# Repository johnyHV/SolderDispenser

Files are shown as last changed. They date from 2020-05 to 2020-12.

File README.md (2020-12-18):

# Solder paste dispenser

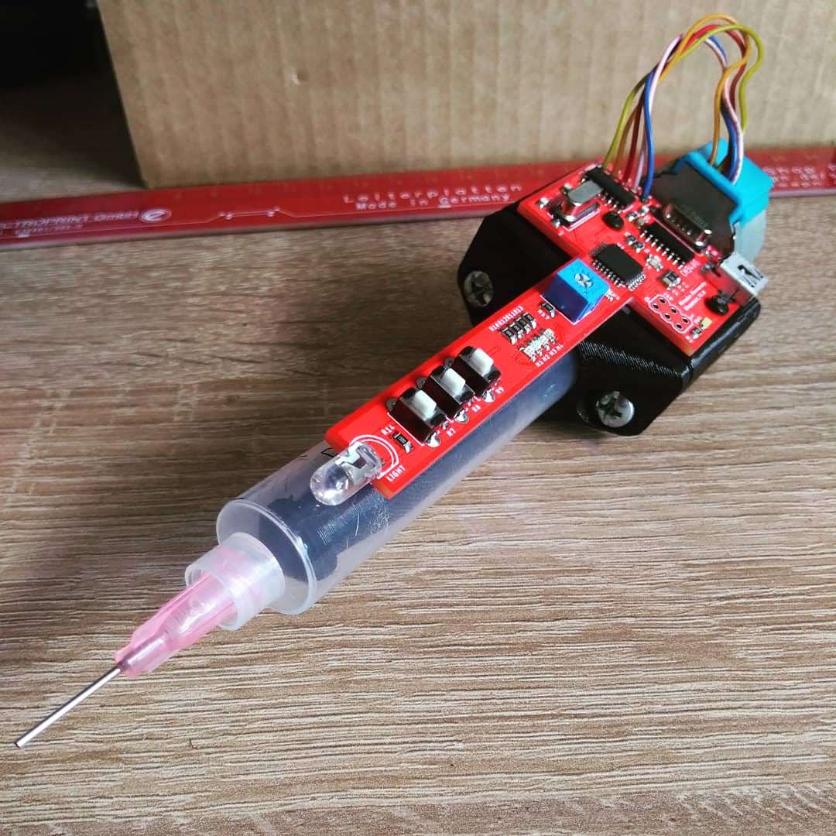
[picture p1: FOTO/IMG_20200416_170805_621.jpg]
Image description


# Change Log

### Version 1.1 [HW v1.1, SW v1.1]
- pridana funkcia auto pull efektu. Toznamena, ze po pusteni PUSH tlacidla sa krokovy motor otoci o X krokov spat, vdaka comu prestane tlacit na spajkovaciu pastu. Efekt mozete zapnut pomocou definicie **M_A_PULL_E** v subore **MCU_cfg.h**.  Definiciou **M_A_PULL_ST** nastavujete pocet krokov o kolko sa krokov motor vrati spet. Tuto hodnotu je potrebne odladit pre kazdeho uzivatela, no myslim ze 100 krokov bude dost. Definiciou **M_A_PULL_SP** nastavite rychlost otacania krokoveho motora, pri otacani.
- pridany vypis SW verzie do konzoly
- aktualizovana doxygen dokumentacia

### Version 1.2 [HW v1.1, SW v1.2]
- pridana moznost zapnutia/vypnutia auto pull modu pomocou tlacidiel.  Defaultne je auto pull mod vypnuty, pomocou definicie **M_A_PULL_E**. Pre zapnutie je potrebne podrzat 5 sekund tlacidlo **MODE**. Po 5 sekundach zsvieti led **STATUS** na 1 sekundu. Vtedy je potrebne pustit tlacidlo **MODE**. Touto sekvenciou bol zapnuty auto pull mod. Ak ho chcete vypnut, znova je potrebne podrzat 5 sekund tlacidlo  **MODE**. Volba zapnutia/vypnutia auto pull modu sa neuklada do EEPROM pamete, cize po kazdom restarte je nastavena na hodnotu v definicii **M_A_PULL_E**.
- aktualizacia doxygen dokumentacie

### Version 1.3 [HW v1.2, SW v1.2]
- pridany kondenzator 1uF k napajaniu MCU

### Version 1.4 [HW v1.3, SW v1.2]
- pridany kondenzator 100nF k CH340 na 3,3V vystup.

# Bug

### Bug 0001
**Opis chyby:** 
chyba v HW zapojeni pre HW verzie 1.0, 1.1, 1.2. Chybajuci kondenzator 100nF pre CH340 na pine 4, proti zemi.

**Spravanie chyby:**
- OS moze mat problem pri detegcii zariadenia, v pripade pouzitia dlheho USB kabla. Pri dlzke kabla do 20cm bude zariadenie fungovat korektne.
- Moze vzniknut problem pri programovani MCU, kedy OS vypise hlasku nedetegovaneho USB zariadenia.
- Nahodne restarty MCU pocas pouzivania podavaca

**Riesenie:**
- potrebne prispajkovat kondenzator 100nF na pin 4 integrovaneho obvodu CH340 proti zemi. Tak ako je to zobrazene na fotografii
Image description

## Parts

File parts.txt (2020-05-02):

https://www.tme.eu/sk/details/b4_bn1052/zavitove-vlozky/bossard/m4-bn1052/
https://www.tme.eu/sk/details/mx-54819-0519/konektory-usb-a-ieee1394/molex/54819-0519/
https://www.tme.eu/sk/details/3362p-1-103lf/potenciometre-jednootackove-tht/bourns/
https://www.tme.eu/sk/details/uln2003adr/drivery-integrovane-obvody/texas-instruments/
https://www.tme.eu/sk/details/1825965-1/ostatne-prepinace-a-kontrolky/te-connectivity/
https://www.tme.eu/sk/details/16.00m-smdhc49s-ht/krystalove-rezonatory-smd/yic/16mhz-105c-49smd-on-tape/
https://www.tme.eu/sk/details/12.00m-smdhc49s/krystalove-rezonatory-smd/yic/
https://www.tme.eu/sk/details/b4x20_bn1435/skrutky/bossard/1219995/
https://www.tme.eu/sk/details/c0805c220j5gac/kondenzatory-mlcc-smd-0805/kemet/c0805c220j5gactu/

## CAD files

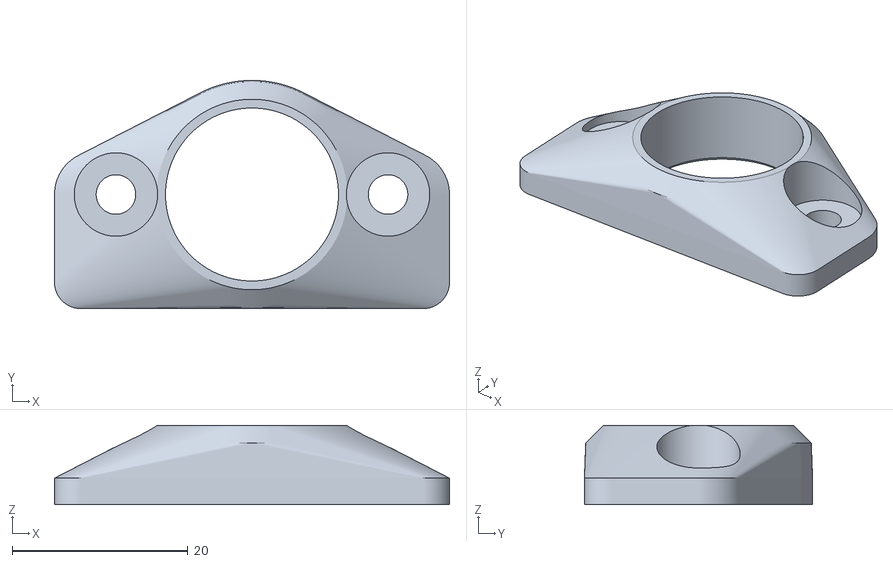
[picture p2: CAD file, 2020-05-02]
3D/syringe_18.6mm.stl
45.0 x 26.0 x 9.00

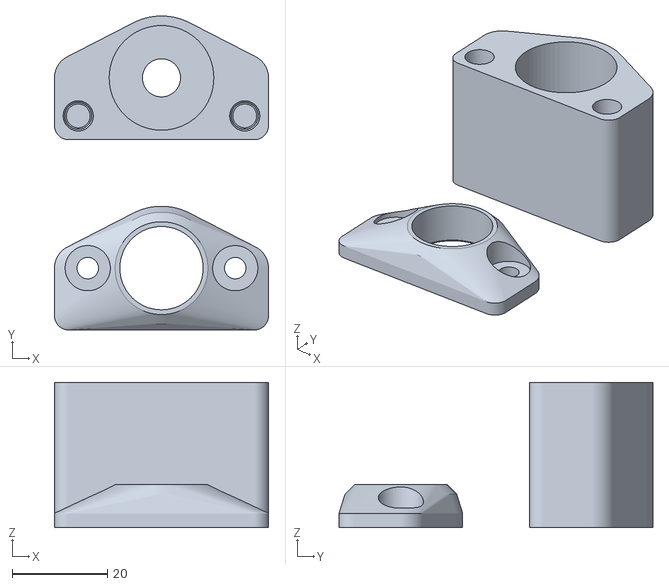
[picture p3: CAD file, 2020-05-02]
3D/motor_mount.stl
45.0 x 66.0 x 30.5

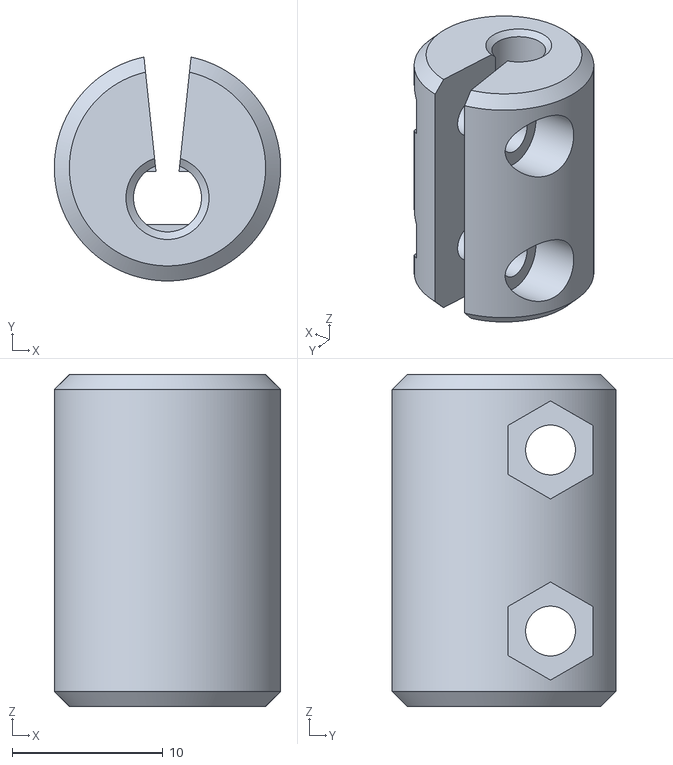
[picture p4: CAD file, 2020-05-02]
3D/coupler.stl
15.0 x 14.8 x 22.0

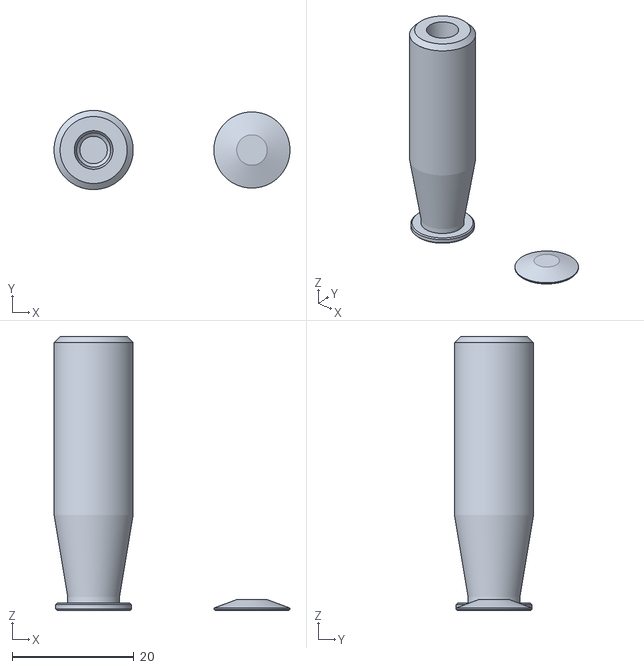
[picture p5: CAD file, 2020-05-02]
3D/plunger.stl
38.8 x 13.0 x 45.0

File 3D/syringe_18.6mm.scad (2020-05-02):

// This file generates two parts, the motor mount and a matching syringe holder plate.
// The motor mount has holes for 4 M4 threaded inserts, McMaster 94180A353. Push them
// in with a standard solder iron. Make sure to push 1-2 mm at a time, letting the 
// plastic part to cool down.

$fn=180;

shaft_hole_diameter = 8;

bottom_height = 2.5;
motor_mount_width = 45;

cavity_wall = 2;
cavity_height = 28;
cavity_diameter = 22;

motor_screws_space = 35;
motor_screws_holes_offset = 8;
motor_screws_holes_depth = 20;

syringe_screws_space = 31;
syringe_screws_holes_depth = 20;

total_height = bottom_height + cavity_height;

base_corner_radius1 = 5;  // convex side
base_corner_radius2 = 3;  // flat side
base_corner_offset  = 0;

syringe_holder_height1 = 3;
syringe_holder_height2 = 6;
syringe_hole_diameter = 18.7+1.0;
syringe_hole_wall = 3;

syringe_holder_screw_diameter = 4.0+0.5;
syringe_holder_screw_head_diameter = 9.0+0.5;

chamfer = 0.5;

eps1 = 0.001;
eps2 = 2*eps1;

// Hole for a M4 metal insert, mcmaster part number 94180A353.
// h is the total depth for the screw hole. Already includes an 
// extra eps1 at the opening side.
module m4_threaded_insert(h) {
  // Adding tweaks for compensate for my printer's tolerace.
  A = 5.3 + 0.3;
  B = 5.94 + 0.4;
  L = 7.9;
  D = 5.0;
  translate([0, 0, -eps1]) {
    // NOTE: diameter are compensated to actual print results.
    // May vary among printers.
    cylinder(d1=B, d2=A, h=eps1+L*2/3, $f2=32);
    cylinder(d=A, h=eps1+L, $f2=32);
    translate([0, 0, L-eps1]) cylinder(d=D, h=h+eps1-L, $f2=32);
  }
}

// c1, c2 are chamfers at bottom and top respectivly. s1, s2 are chamfers's slopes.
module chamfered_cylinder(d, h, c1, s1, c2, s2) {
    cylinder(d1=d-2*c1, d2=d, h=s1*c1);
    translate([0, 0, s1*c1-eps1]) cylinder(d=d, h=h-s1*c1-s2*c2+eps2);
    translate([0, 0, h-s2*c2]) cylinder(d1=d, d2=d-2*c2, h=s2*c2);
}

module motor_holes() {
  translate([motor_screws_space/2, -motor_screws_holes_offset, total_height]) 
      rotate([180, 0, 0]) 
      m4_threaded_insert(motor_screws_holes_depth);

 translate([-motor_screws_space/2, -motor_screws_holes_offset, total_height]) 
      rotate([180, 0, 0]) 
      m4_threaded_insert(motor_screws_holes_depth);
}

module syringe_screws() {
  translate([syringe_screws_space/2, 0, -eps1]) 
      m4_threaded_insert(syringe_screws_holes_depth);
  
  translate([-syringe_screws_space/2, 0, -eps1]) 
       m4_threaded_insert(syringe_screws_holes_depth);
}

// Hole at the bottom of the base for the shreded shaft.
module shaft_hole() {
 translate([0, 0, -eps1]) cylinder(d=shaft_hole_diameter, h=bottom_height+eps2, $f2=32);
}

// The motor mount before any substraction. It accepts a height parameter so 
// we can use this pattern also for the syringe holder.
module base_pattern(h) {
  hull() {
    cylinder(d=cavity_diameter+2*cavity_wall, h=h);
    
    // Flat side
    translate([motor_mount_width/2-base_corner_radius2, -(cavity_diameter+2*cavity_wall)/2+base_corner_radius2, 0]) cylinder(r=base_corner_radius2, h=h);
    
    translate([-(motor_mount_width/2-base_corner_radius2), -(cavity_diameter+2*cavity_wall)/2+base_corner_radius2, 0]) cylinder(r=base_corner_radius2, h=h);
    
    // Concave side
    translate([motor_mount_width/2-base_corner_radius1, base_corner_offset, 0]) 
        cylinder(r=base_corner_radius1, h=h);
    
    translate([-(motor_mount_width/2-base_corner_radius1), base_corner_offset, 0]) 
        cylinder(r=base_corner_radius1, h=h);
  }
}

// The coupler cavity cut.
module cavity() {
  translate([0, 0, bottom_height]) cylinder(d=cavity_diameter, h=total_height, $fn=64);  
}

module motor_mount() {
  difference() {
    base_pattern(total_height);
    cavity();
    shaft_hole();
    motor_holes();
    syringe_screws();
  }
}

module syringe_holder_blank() {
  hull() {
    translate([0, 0, syringe_holder_height1]) rotate([0, 180, 0]) 
        base_pattern(syringe_holder_height1);
  
    chamfered_cylinder(syringe_hole_diameter+2*syringe_hole_wall, syringe_holder_height1+syringe_holder_height2, eps1, 1.0, 2.0, 1.0);
  } 
}

module syringe_holder() {
  total_h=syringe_holder_height1+syringe_holder_height2+eps2;
  difference() {
    syringe_holder_blank();
    
    // Syringe hole + chamfer;
    translate([0, 0, -eps1]) {
      cylinder(d=syringe_hole_diameter, h=total_h+eps2);
      cylinder(d1=syringe_hole_diameter + 2*chamfer, d2=eps1, 
          h=(syringe_hole_diameter + 2*chamfer)/2);
    }
    
    
    
    // Screw holes + chamfers.
    translate([-syringe_screws_space/2, 0, -eps1]) {
      cylinder(d=syringe_holder_screw_diameter, h=total_h+eps2);
      cylinder(d1=syringe_holder_screw_diameter + 2*chamfer, d2=eps1, 
          h=(syringe_holder_screw_diameter + 2*chamfer)/2);
    }
    
    translate([syringe_screws_space/2, 0, -eps1]) {
      cylinder(d=syringe_holder_screw_diameter, h=total_h+eps2);
      cylinder(d1=syringe_holder_screw_diameter + 2*chamfer, d2=eps1, 
          h=(syringe_holder_screw_diameter + 2*chamfer)/2);
    }
    
    // Screw heads insets.
    translate([-syringe_screws_space/2, 0, syringe_holder_height1]) 
        cylinder(d=syringe_holder_screw_head_diameter, h=syringe_holder_height2+eps2);
    
    translate([syringe_screws_space/2, 0, syringe_holder_height1]) 
        cylinder(d=syringe_holder_screw_head_diameter, h=syringe_holder_height2+eps2);
  }  
}

module main() {
  //motor_mount();
  translate([0, -40, 0]) syringe_holder();
}

main();

 

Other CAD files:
3D/motor_mount.scad
3D/coupler.scad
3D/plunger.scad

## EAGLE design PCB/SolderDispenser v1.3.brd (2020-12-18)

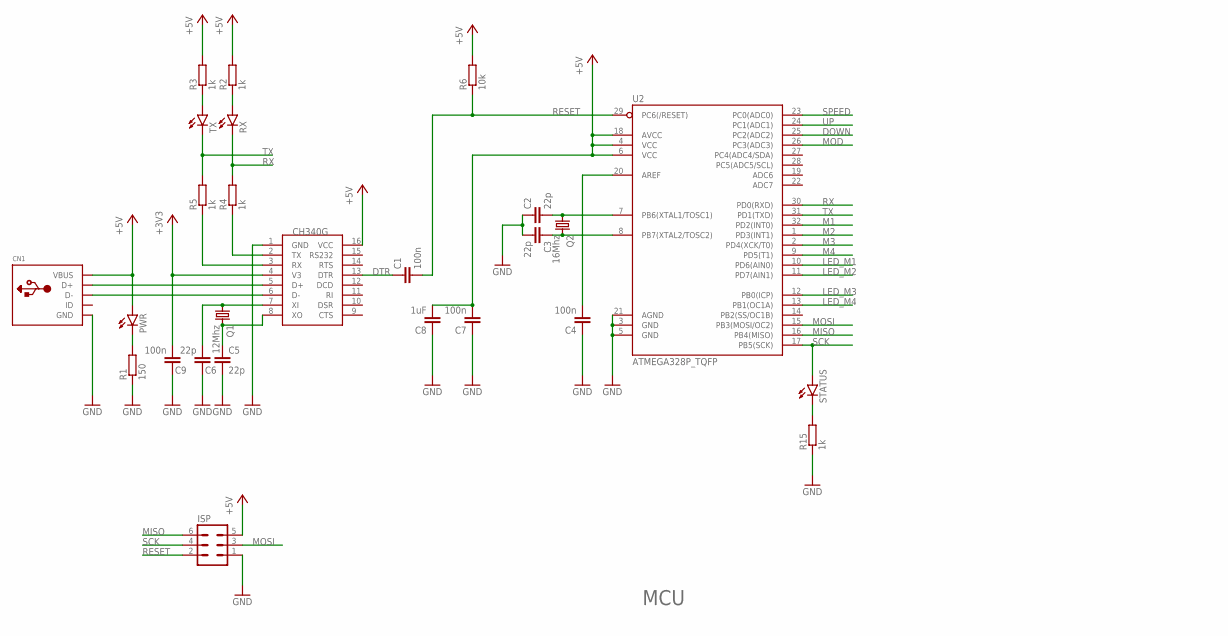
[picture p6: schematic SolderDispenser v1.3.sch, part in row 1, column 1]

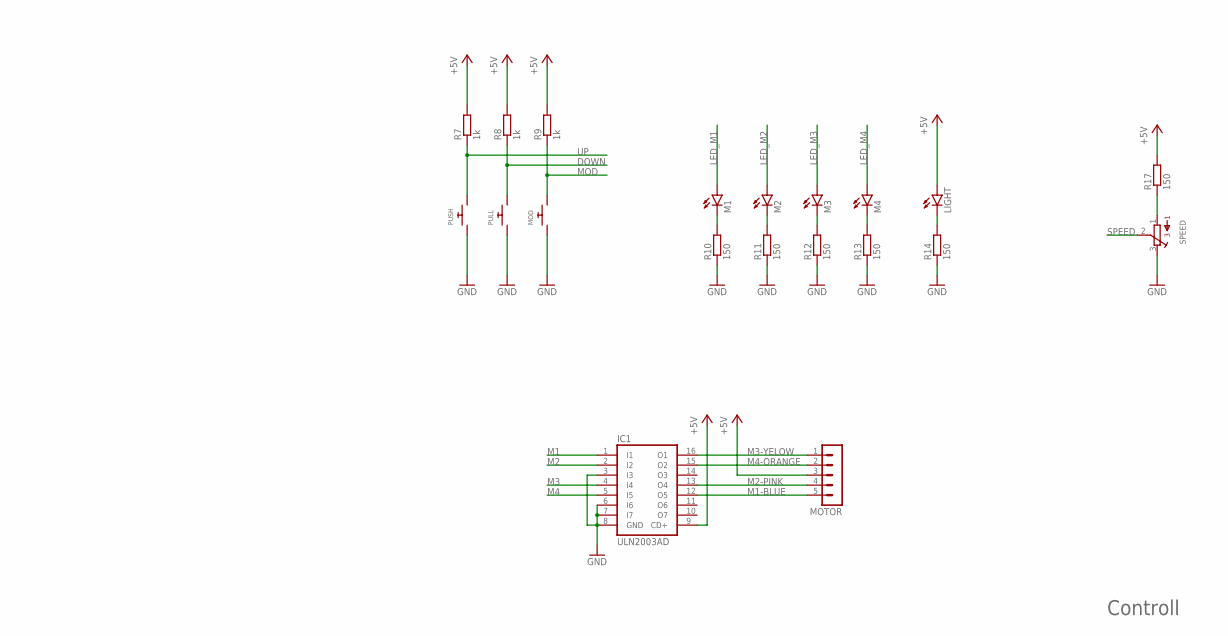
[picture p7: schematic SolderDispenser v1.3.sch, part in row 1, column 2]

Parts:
C1, C4, C7, C9: 100n; C0805
C2, C3, C5, C6: 22p; C0805
C8: 1uF; C0805
CN1: USBMOLEX; USB-MINIB-THM-MOLEX
IC1: ULN2003AD; SO16
ISP: MA03-2
LIGHT: LED5MM
M1, M2, M3, M4: LEDSML0805; SML0805
MOD: SWITCH_PUSHBUTTONEVQ-PE; TACT_PANA-EVQ
MOTOR: MA05-1
PULL: SWITCH_PUSHBUTTONEVQ-PE; TACT_PANA-EVQ
PUSH: SWITCH_PUSHBUTTONEVQ-PE; TACT_PANA-EVQ
PWR: LEDSML0805; SML0805
Q1: 12Mhz; HC49UP
Q2: 16Mhz; HC49UP
R1, R10, R11, R12, R13, R14, R17: 150; R0805
R2, R3, R4, R5, R7, R8, R9, R15: 1k; R0805
R6: 10k; R0805
RX: LEDSML0805; SML0805
SPEED: 3362P
STATUS: LEDSML0805; SML0805
TX: LEDSML0805; SML0805
U2: ATMEGA328P_TQFP; TQFP32-08
U$1: CH340G; SOIC16

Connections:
+3V3: C9.2, U$1.4 (V3)
+5V: C7.2, C8.2, CN1.VBUS, IC1.9 (CD+), ISP.5, LIGHT.A, MOTOR.3, PWR.A, R2.2, R3.2, R6.2, R7.2, R8.2, R9.2, R17.2, U2.4 (VCC), U2.6 (VCC), U2.18 (AVCC), U$1.16 (VCC)
DOWN: PULL.P$2, R8.1, U2.25 (PC2(ADC2))
DTR: C1.1, U$1.13 (DTR)
GND: C2.1, C3.2, C4.1, C5.2, C6.1, C7.1, C8.1, C9.1, CN1.GND, IC1.3 (I3), IC1.6 (I6), IC1.7 (I7), IC1.8 (GND), ISP.1, MOD.P$1, PULL.P$1, PUSH.P$1, R1.1, R10.1, R11.1, R12.1, R13.1, R14.1, R15.1, SPEED.3, U2.3 (GND), U2.5 (GND), U2.21 (AGND), U$1.1 (GND)
LED_M1: M1.A, U2.10 (PD6(AIN0))
LED_M2: M2.A, U2.11 (PD7(AIN1))
LED_M3: M3.A, U2.12 (PB0(ICP))
LED_M4: M4.A, U2.13 (PB1(OC1A))
M1: IC1.1 (I1), U2.32 (PD2(INT0))
M1-BLUE: IC1.12 (O5), MOTOR.5
M2: IC1.2 (I2), U2.1 (PD3(INT1))
M2-PINK: IC1.13 (O4), MOTOR.4
M3: IC1.4 (I4), U2.2 (PD4(XCK/T0))
M3-YELOW: IC1.16 (O1), MOTOR.1
M4: IC1.5 (I5), U2.9 (PD5(T1))
M4-ORANGE: IC1.15 (O2), MOTOR.2
MISO: ISP.6, U2.16 (PB4(MISO))
MOD: MOD.P$2, R9.1, U2.26 (PC3(ADC3))
MOSI: ISP.3, U2.15 (PB3(MOSI/OC2))
unnamed: CN1.D+, U$1.5 (D+)
unnamed: PWR.C, R1.2
unnamed: CN1.D-, U$1.6 (D-)
unnamed: R5.1, U$1.3 (RX)
unnamed: R4.1, U$1.2 (TX)
unnamed: C2.2, Q2.1, U2.7 (PB6(XTAL1/TOSC1))
unnamed: C6.2, Q1.1, U$1.7 (XI)
unnamed: C5.1, Q1.2, U$1.8 (XO)
unnamed: R2.1, RX.A
unnamed: R3.1, TX.A
unnamed: C3.1, Q2.2, U2.8 (PB7(XTAL2/TOSC2))
unnamed: C4.2, U2.20 (AREF)
unnamed: M1.C, R10.2
unnamed: LIGHT.K (C), R14.2
unnamed: M2.C, R11.2
unnamed: R15.2, STATUS.C
unnamed: M3.C, R12.2
unnamed: M4.C, R13.2
unnamed: R17.1, SPEED.1
RESET: C1.2, ISP.2, R6.1, U2.29 (PC6(/RESET))
RX: R4.2, RX.C, U2.30 (PD0(RXD))
SCK: ISP.4, STATUS.A, U2.17 (PB5(SCK))
SPEED: SPEED.2, U2.23 (PC0(ADC0))
TX: R5.2, TX.C, U2.31 (PD1(TXD))
UP: PUSH.P$2, R7.1, U2.24 (PC1(ADC1))

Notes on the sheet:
MCU
Controll

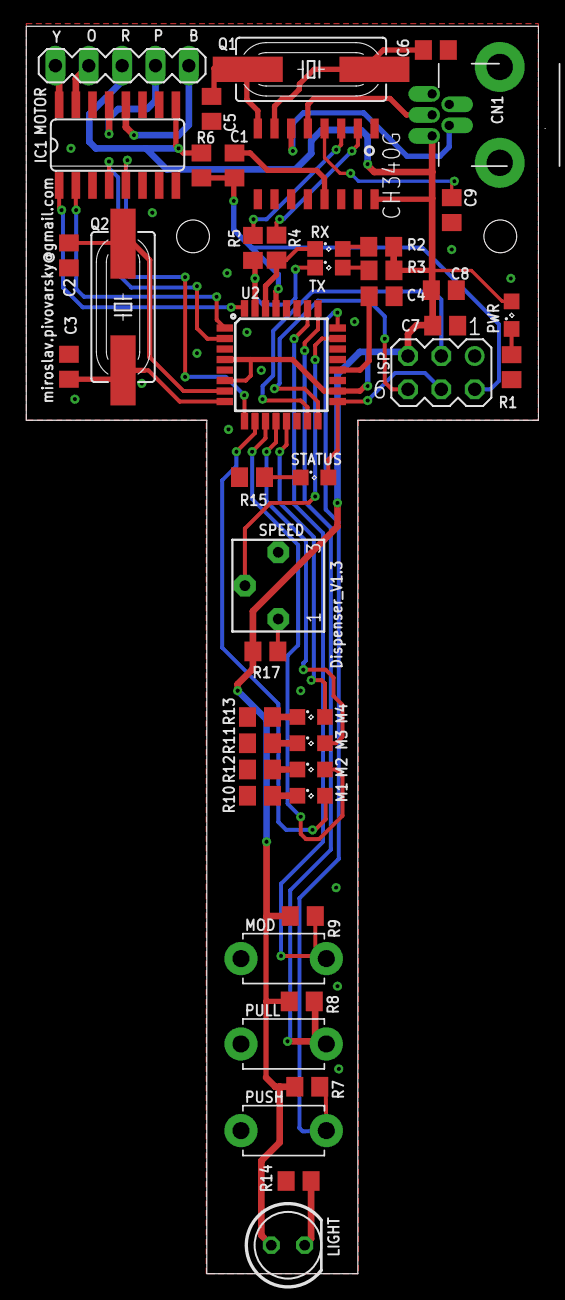
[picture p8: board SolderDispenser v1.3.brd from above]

Board: 2 copper layers, 39.0 x 95.0 mm, 46 parts (0 on the bottom side), 45 nets.

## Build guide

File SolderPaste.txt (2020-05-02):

XG-50	Sn63/Pb37 				25-45um 
XG-Z40	Sn63/Pb37 				25-45um
BR508 	Sn63/Pb37
XG-z40	Sn63/Pb37 				25-45um
XGS40	Sn62.6/Pb37.0/Ag0.40	20-38um
XP5 	Sn63/Pb37				20-38µm
RL-402	Sn63/Pb37				20-38um

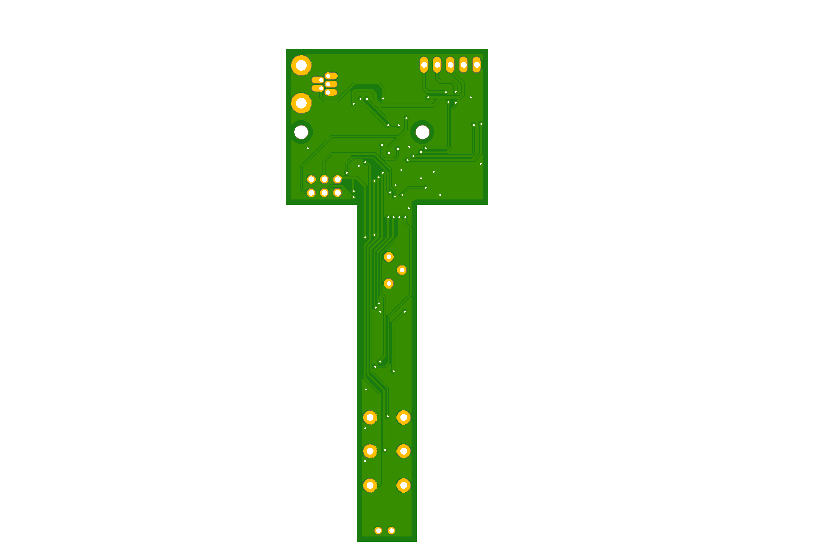
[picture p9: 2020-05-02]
FOTO/SolderDispenser v1.1_botton.png

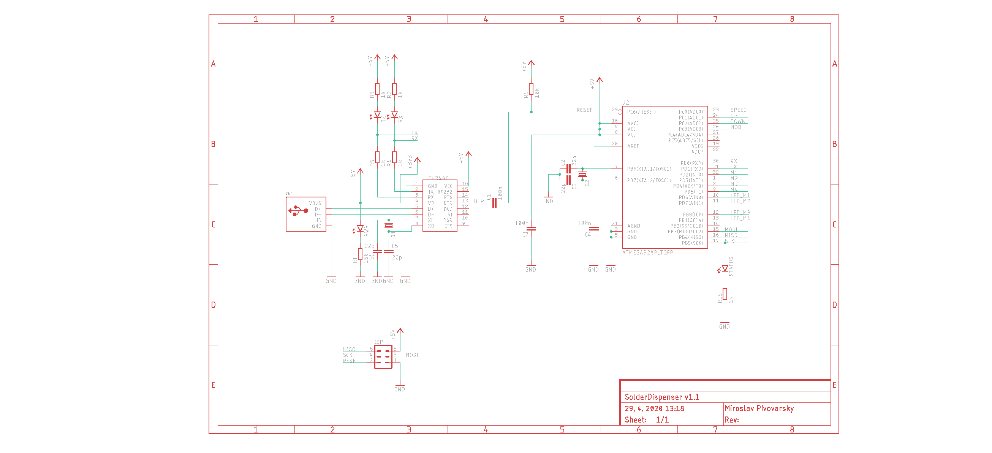
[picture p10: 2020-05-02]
FOTO/SolderDispenser v1.1_sch_MCU.png

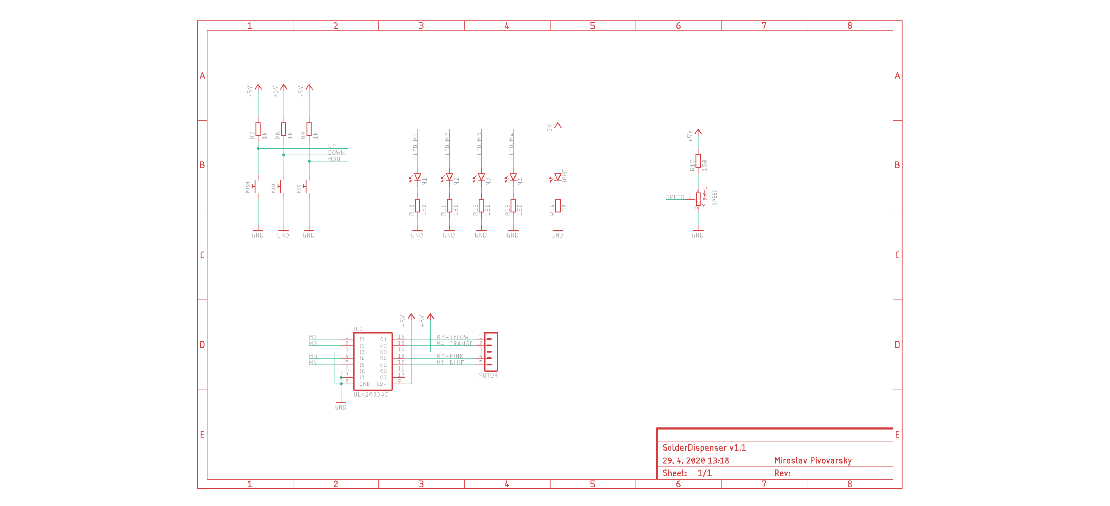
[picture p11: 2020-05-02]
FOTO/SolderDispenser v1.1_sch_Controll.png

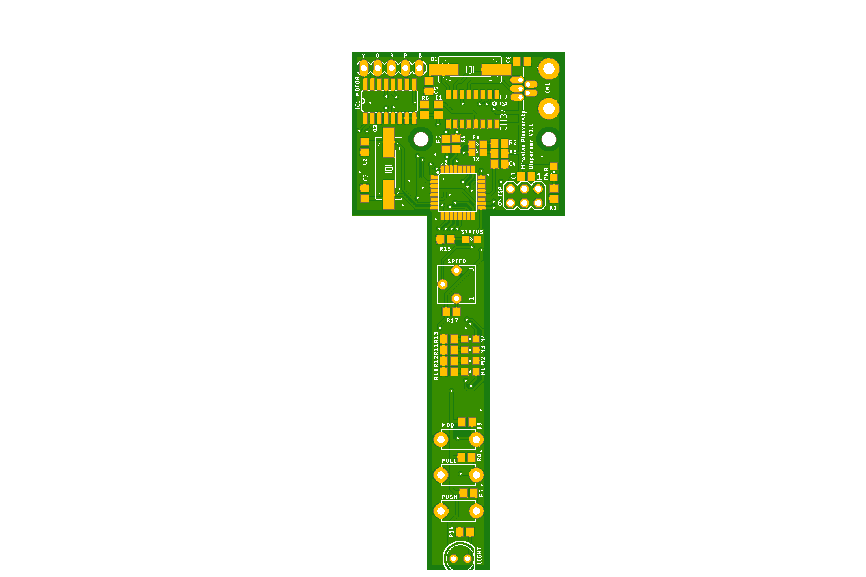
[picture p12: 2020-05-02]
FOTO/SolderDispenser v1.1_TOP.png

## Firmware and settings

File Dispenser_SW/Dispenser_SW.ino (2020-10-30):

#include <Arduino.h>
#include <EEPROM.h>

#include "StepperMotor.h"
#include "Config.h"

void setup() {
  Serial.begin(115200);
  Serial.println("Start MCU!");
  Serial.print("Software version: ");
  Serial.println(SOFTWARE_VERSION);

  /* inicializacia motora */
  MotorInit();

  /* inicializacia periferii  */
  ConfigInit();
  ConfigCheckButtonMod();
  delay(Mode_debounceDelay * 2);
  ConfigCheckButtonMod();

  /* nastavenie modu 1 */
  ConfigSetMod(1);

  /* nastavenie casu oneskorenia zopnutia dalsiej cievky */
  MotorSetSleep(ConfigEepromRead(E_MOD1));

}

void loop() {

  /* kontrola zapnutia/vypnutia auto pull efektu */
  if (ConfigCheckButtonModAutoPullEffect() == true) {
    MotorAutoPullEnDis(!MotorAutoPullStatus());

  } else {

    /* kontrola tlacidla pre zmenu modu */
    if (ConfigCheckButtonMod() == true) {
      ConfigModeStatus++;

      if (ConfigModeStatus > 5)
        ConfigModeStatus = 1;

      ConfigSetMod(ConfigModeStatus);
    }
  }

  /* kontrola tlacidiel pre ovladanie motora */
  if (ConfigCheckButtonPush() == false) {
    MotorStepper(MOTOR_PUSH);
    MotorAutoPull = MOTOR_PUSH;
  } else if (ConfigCheckButtonPull() == false) {
    MotorStepper(MOTOR_PULL);
    MotorAutoPull = MOTOR_PULL;
  } else {
    MotorOff();

    /* auto pull efekt, cize po pusteni PUSH tlacidla sa motor sam otoci spet o X krokov, aby netlacil na pastu */
    if (MotorAutoPull == MOTOR_PUSH) {
      Serial.print("Auto pull efekt: ");
      MotorAutoPullEffect();
    }
  }

  /* specialny mod pre citanie rychlosti z trimra */
  if (ConfigModeStatus == 5) {
    MotorSetSleep(ConfigGetTime());
  }
}

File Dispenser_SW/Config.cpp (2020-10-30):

/**
   @file Config.cpp

   @brief kniznica s logikou

   @author Miroslav Pivovarsky
   Contact: miroslav.pivovarsky@gmail.com

   @bug: no know bug

*/

#include "Config.h"

uint8_t Mode_buttonState = LOW;
uint8_t Mode_lastButtonState = LOW;
unsigned long Mode_lastDebounceTime = 0;
unsigned long Mode_lastDebounceTimeAutoPull = 0;
uint8_t ConfigModeStatus = 1;
uint8_t AutoPullSafety = false;

/**

   @info Inicializacia periferii
   @param none
   @return none
*/
void ConfigInit() {
  pinMode(LED_1, OUTPUT);
  pinMode(LED_2, OUTPUT);
  pinMode(LED_3, OUTPUT);
  pinMode(LED_4, OUTPUT);
  pinMode(LED_STATUS, OUTPUT);

  pinMode(BUTTON_PUSH, INPUT);
  pinMode(BUTTON_PULL, INPUT);
  pinMode(BUTTON_MOD, INPUT);

  digitalWrite(LED_1, LOW);
  digitalWrite(LED_2, LOW);
  digitalWrite(LED_3, LOW);
  digitalWrite(LED_4, LOW);
  digitalWrite(LED_STATUS, LOW);

  Mode_lastButtonState = digitalRead(BUTTON_MOD);
}

/**

   @info nastavenie rychlosti spinania pre dany mod
   @param int - mod
   @return none
*/
void ConfigSetMod(int Mod) {
  switch (Mod) {
    case 1:
      ConfigSetLed(1);
      MotorSetSleep(ConfigEepromRead(E_MOD1));
      break;
    case 2:
      ConfigSetLed(2);
      MotorSetSleep(ConfigEepromRead(E_MOD2));
      break;
    case 3:
      ConfigSetLed(3);
      MotorSetSleep(ConfigEepromRead(E_MOD3));
      break;
    case 4:
      ConfigSetLed(4);
      MotorSetSleep(ConfigEepromRead(E_MOD4));
      break;
    case 5:
      ConfigSetLed(5);
      break;
  }
}

/**

   @info zapnutie konkretnej LED-ky pre dany mod
   @param int - led
   @return none
*/
void ConfigSetLed(int led) {
  switch (led) {
    case 1:
      digitalWrite(LED_1, HIGH);
      digitalWrite(LED_2, LOW);
      digitalWrite(LED_3, LOW);
      digitalWrite(LED_4, LOW);
      break;
    case 2:
      digitalWrite(LED_1, LOW);
      digitalWrite(LED_2, HIGH);
      digitalWrite(LED_3, LOW);
      digitalWrite(LED_4, LOW);
      break;
    case 3:
      digitalWrite(LED_1, LOW);
      digitalWrite(LED_2, LOW);
      digitalWrite(LED_3, HIGH);
      digitalWrite(LED_4, LOW);
      break;
    case 4:
      digitalWrite(LED_1, LOW);
      digitalWrite(LED_2, LOW);
      digitalWrite(LED_3, LOW);
      digitalWrite(LED_4, HIGH);
      break;
    case 5:
      digitalWrite(LED_1, HIGH);
      digitalWrite(LED_2, HIGH);
      digitalWrite(LED_3, HIGH);
      digitalWrite(LED_4, HIGH);
      break;
  }
}

/**

   @info Kontrola stlacenia PUSH tlacidla
   @param none
   @return bool - status tlacidla
*/
bool ConfigCheckButtonPush() {
  return digitalRead(BUTTON_PUSH);
}

/**

   @info Kontrola stlacenia PULL tlacidla
   @param none
   @return bool - status tlacidla
*/
bool ConfigCheckButtonPull() {
  return digitalRead(BUTTON_PULL);
}

/**

   @info Kontrola stlacenia tlacidla mode, pre zmenu rychlosti alebo zapis do EEPROM
   @param none
   @return bool - status tlacidla
*/
bool ConfigCheckButtonMod() {
  int Mode_reading = digitalRead(BUTTON_MOD);

  if (Mode_reading != Mode_lastButtonState) {
    Mode_lastDebounceTime = millis();
  }

  /* kontrola, ci tlacidlo bolo dostatocne dlho stlacene */
  if ((millis() - Mode_lastDebounceTime) > Mode_debounceDelay) {

    if (Mode_reading != Mode_buttonState) {
      Mode_buttonState = Mode_reading;

      /* kontrola, ci je stlacene aj PULL tlacidlo, a ci ide o zapis hodnoty do EEPROM pamete pre dany mod */
      if ((ConfigCheckButtonPull() == false) && (Mode_buttonState == HIGH)) {
        digitalWrite(LED_STATUS, HIGH);

        int value = ConfigGetTime();
        Serial.print("Analog: ");
        Serial.println(value);
        switch (ConfigModeStatus) {
          case 1:
            ConfigEepromWrite(E_MOD1, value);
            break;
          case 2:
            ConfigEepromWrite(E_MOD2, value);
            break;
          case 3:
            ConfigEepromWrite(E_MOD3, value);
            break;
          case 4:
            ConfigEepromWrite(E_MOD4, value);
            break;
        }

        ConfigSetMod(ConfigModeStatus);
        Mode_lastButtonState = Mode_reading;
        delay(500);
        digitalWrite(LED_STATUS, LOW);
        return false;
      }

      if (Mode_buttonState == HIGH) {
        return true;
      }
    }
  }

  Mode_lastButtonState = Mode_reading;
  return false;
}
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

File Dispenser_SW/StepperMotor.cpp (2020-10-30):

/**
   @file StepperMotor.cpp

   @brief Ovladanie krokoveho motora

   @author Miroslav Pivovarsky
   Contact: miroslav.pivovarsky@gmail.com

   @bug: no know bug

*/

#include "StepperMotor.h"

int MotorSteps = 0;
uint16_t MotorSleep = 0;
uint8_t MotorAutoPull = MOTOR_STOP;
uint8_t MotorAutoPullEn = M_A_PULL_E;

/**

   @info Inicializacia motora
   @param none
   @return none
*/
void MotorInit() {
  pinMode(MOTOR_M1, OUTPUT);
  pinMode(MOTOR_M2, OUTPUT);
  pinMode(MOTOR_M3, OUTPUT);
  pinMode(MOTOR_M4, OUTPUT);
}

/**

   @info Nastavenie rychlosti spinania cievok
   @param uint16_t - rychlost v uS
   @return none
*/
void MotorSetSleep(uint16_t val) {
  MotorSleep = val;
}

/**

   @info Ziskam aktualnu medzeru medzi krokmi v uS
   @param none
   @return uint16_t - rychlost v uS
*/
uint16_t MotorGetSleep() {
  return MotorSleep;
}

/**

   @info Funkcia pre spinanie cievok krokoveho motora
   @param uint8_t - smer motora
   @return none
*/
void MotorStepper(uint8_t Direction) {
  switch (MotorSteps) {
    case 0:
      digitalWrite(MOTOR_M1, LOW);
      digitalWrite(MOTOR_M2, LOW);
      digitalWrite(MOTOR_M3, LOW);
      digitalWrite(MOTOR_M4, HIGH);
      break;
    case 1:
      digitalWrite(MOTOR_M1, LOW);
      digitalWrite(MOTOR_M2, LOW);
      digitalWrite(MOTOR_M3, HIGH);
      digitalWrite(MOTOR_M4, HIGH);
      break;
    case 2:
      digitalWrite(MOTOR_M1, LOW);
      digitalWrite(MOTOR_M2, LOW);
      digitalWrite(MOTOR_M3, HIGH);
      digitalWrite(MOTOR_M4, LOW);
      break;
    case 3:
      digitalWrite(MOTOR_M1, LOW);
      digitalWrite(MOTOR_M2, HIGH);
      digitalWrite(MOTOR_M3, HIGH);
      digitalWrite(MOTOR_M4, LOW);
      break;
    case 4:
      digitalWrite(MOTOR_M1, LOW);
      digitalWrite(MOTOR_M2, HIGH);
      digitalWrite(MOTOR_M3, LOW);
      digitalWrite(MOTOR_M4, LOW);
      break;
    case 5:
      digitalWrite(MOTOR_M1, HIGH);
      digitalWrite(MOTOR_M2, HIGH);
      digitalWrite(MOTOR_M3, LOW);
      digitalWrite(MOTOR_M4, LOW);
      break;
    case 6:
      digitalWrite(MOTOR_M1, HIGH);
      digitalWrite(MOTOR_M2, LOW);
      digitalWrite(MOTOR_M3, LOW);
      digitalWrite(MOTOR_M4, LOW);
      break;
    case 7:
      digitalWrite(MOTOR_M1, HIGH);
      digitalWrite(MOTOR_M2, LOW);
      digitalWrite(MOTOR_M3, LOW);
      digitalWrite(MOTOR_M4, HIGH);
      break;
    default:
      digitalWrite(MOTOR_M1, LOW);
      digitalWrite(MOTOR_M2, LOW);
      digitalWrite(MOTOR_M3, LOW);
      digitalWrite(MOTOR_M4, LOW);
      break;
  }
  SetDirection(Direction);
  delayMicroseconds(MotorSleep);
}

/**

   @info Vypnutie krokoveho motora
   @param none
   @return none
*/
void MotorOff() {
  digitalWrite(MOTOR_M1, LOW);
  digitalWrite(MOTOR_M2, LOW);
  digitalWrite(MOTOR_M3, LOW);
  digitalWrite(MOTOR_M4, LOW);
}

/**

   @info Nastavenie smeru otacania motora
   @param int - smer
   @return none
*/
void SetDirection(uint8_t Direction) {

  if (Direction == MOTOR_PUSH) {
    MotorSteps--;
  }
  if (Direction == MOTOR_PULL) {
    MotorSteps++;
  }

  if (MotorSteps > 7) {
    MotorSteps = 0;
  }
  if (MotorSteps < 0) {
    MotorSteps = 7;
  }
}

/**

   @info efekt automaticke povytiahnutia piestu, aby sa netlacila stale pasta
   @param none
   @return none
*/
void MotorAutoPullEffect() {
  
  if (MotorAutoPullEn == true) {
    Serial.println("Enable");
    uint16_t LastSpeed = MotorGetSleep();

    MotorSetSleep(M_A_PULL_SP);
    for (uint8_t i = 0; i <= M_A_PULL_ST; i++) {
      Serial.println(i);
      MotorStepper(MOTOR_PULL);
    }

    MotorOff();
    MotorSetSleep(LastSpeed);
  } else {
    Serial.println("Disable");
  }
  
  
  MotorAutoPull = MOTOR_STOP;
}

/**

   @info Nastavenie auto pull efektu cez mode button
   @param status modu
   @return none
*/
void MotorAutoPullEnDis(uint8_t input) {
  Serial.print("Pull status: ");
  Serial.println(input);
  MotorAutoPullEn = input;
}

uint8_t MotorAutoPullStatus() {
  return MotorAutoPullEn;
}

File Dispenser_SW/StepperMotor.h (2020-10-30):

/**
 * @file StepperMotor.cpp
 *
 * @brief Ovladanie krokoveho motora
 *
 * @author Miroslav Pivovarsky
 * Contact: miroslav.pivovarsky@gmail.com
 * 
 * @bug: no know bug
 *
 */

#ifndef __STEPPER_MOTOR_h_
#define __STEPPER_MOTOR_h_

#include <Arduino.h>
#include "MCU_cfg.h"

extern int  MotorSteps;           ///< aktualna poloha motora
extern uint16_t MotorSleep;       ///< dlzka sleep-u
extern uint8_t MotorAutoPull;     ///< Informacia o tlacidlach pre auto pull efekt
extern uint8_t MotorAutoPullEn;   ///< Aktualny stav zapnutia/vypnutia auto pull efektu cez tlacidlo.

#define MOTOR_PUSH      'F'       ///< priznak pre posun vpred
#define MOTOR_PULL      'B'       ///< priznak pre posun vzad
#define MOTOR_STOP      'S'       ///< priznak pre STOP motor
#define Motor460Steps   4095      ///< pocet krokov

#define MOTOR_MIN       1100      ///< maximalna rychlost spinania
#define MOTOR_MAX       10000     ///< minimalna rychlost spinania

void MotorInit();                 ///< inicializacia motora
void MotorSetSleep(uint16_t);     ///< nastavenie dlzky sleepu medzi dalsim zopnutim cievok
uint16_t MotorGetSleep();         ///< Ziskam aktualnu dlzku casu medzi krokmi
void MotorStepper(uint8_t);       ///< dalsi krok 
void MotorOff();                  ///< vypnutie motora
void SetDirection(uint8_t);       ///< nastavenie smeru motora
void MotorAutoPullEffect();       ///< Automaticky pull efekt o X krokov po pusteni PUSH tlacidla
void MotorAutoPullEnDis(uint8_t); ///< Funkcia pre nastavenie auto pull efektu cez tlacidlo MODE
uint8_t MotorAutoPullStatus();    ///< Informacia ci je aktualne auto pull zapnuty, alebo vypunuty

#endif

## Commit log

2020-05-02 - Add source
    [SolderDispenser v1.0.brd, SolderDispenser v1.0.sch, SolderDispenser v1.1.brd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]
2020-05-02 [3D]
    - Add 3D model for Syringe 18.6mm
    [syringe_18.6mm.scad, syringe_18.6mm.stl]
2020-05-26 [Docu]
    - Add author
    [Graf.xlsx]
2020-10-30 [SW]
    - possibility to switch on the auto pull mode using the MODE button
2020-12-01 [HW]
    - add HW version 1.2
    [Graf.xlsx, SolderDispenser v1.2.brd, SolderDispenser v1.2.sch]
2020-12-18 fix HW bug for CH340 USB to UART converter
    [SolderDispenser v1.3.brd, SolderDispenser v1.3.sch]
2020-12-18 add missing crystal value
    [SolderDispenser v1.1.brd, SolderDispenser v1.1.sch, SolderDispenser v1.2.brd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]

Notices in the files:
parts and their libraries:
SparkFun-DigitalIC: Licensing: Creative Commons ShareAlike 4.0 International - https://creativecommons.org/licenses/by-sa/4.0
